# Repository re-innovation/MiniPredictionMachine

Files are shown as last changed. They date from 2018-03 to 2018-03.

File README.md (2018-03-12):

# MiniPredictionMachine
Arduino based weather sensor unit with solar PV charing and an ESP8266 based receiver unit.

This repository holds the KiCAD PCB design files and the various .dxf files for the hardware.

This repository is for information only and is not maintained.

Please see: https://www.re-innovation.co.uk/ for more information.

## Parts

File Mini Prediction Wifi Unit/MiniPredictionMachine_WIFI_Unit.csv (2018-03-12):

Reference | Value | Footprint | Datasheet | Description | Supplier 1 | Supplier 1 Part No | Supplier 1 Cost | Manufacturer | Manufacturer Part No
U1 | NODEMCU | REInnovationFootprint:NodeMCU_Amica_R2_FSILK
DISP1 | OLED_I2C | REInnovationFootprint:TH_OLED1306
D2 | A | REInnovationFootprint:TH_LED-5MM_larg_pad
D3 | B | REInnovationFootprint:TH_LED-5MM_larg_pad
SW1 | SWUP | REInnovationFootprint:SW_PUSH_SMALL_lg_pad
SW2 | SWDOWN | REInnovationFootprint:SW_PUSH_SMALL_lg_pad
P1 | SERIAL_HC12 | REInnovationFootprint:TH_SIL_5_1mm
R1 | 330 | REInnovationFootprint:TH_Resistor_1
R2 | 330 | REInnovationFootprint:TH_Resistor_1
R4 | 10k | REInnovationFootprint:TH_Resistor_1
R3 | 10k | REInnovationFootprint:TH_Resistor_1
CON1 | BARREL_JACK | REInnovationFootprint:DC_Power_2_1
D1 | WS2811_EpiStar_8mm | REInnovationFootprint:TH_WS2811_LED_8mm
SW3 | ON/OFF | REInnovationFootprint:SW_SPDT_R_Angle_ALIEX
F1 | 500mA | REInnovationFootprint:TH_MC36188_FUSE |  | Resettable fuse. 0.5A | RS | 517-6635 | 0.27
D4 | D_Schottky | REInnovationFootprint:TH_Diode_1
P2 | USB | REInnovationFootprint:TH_USB_B_lg_pad
U2 | L4940V5 | REInnovationFootprint:TO220_7805_Vert | http://docs-europe.electrocomponents.com/webdocs/0028/0900766b80028b09.pdf | 1.5A LDO regulator | RS | 298-8491 |  | STMicroelectronics | L4940V5
D5 | D_Schottky | REInnovationFootprint:TH_Diode_1
C1 | 10u | REInnovationFootprint:C_1V7_TH
C2 | 10u | REInnovationFootprint:C_1V7_TH
P4 | NODEMCU_2 | REInnovationFootprint:TH_SIL-15
P3 | NODEMCU_1 | REInnovationFootprint:TH_SIL-15
U3 | 74LVC1G17 | REInnovationFootprint:SM_SOT-23-5 | http://docs-europe.electrocomponents.com/webdocs/154d/0900766b8154d6d1.pdf
P5 | LOCAL 5V? | matts_components:SIL-2_solder_connect
P6 | WS2812 LED | matts_components:SIL-4_screw_terminals
P7 | PCB | REInnovationFootprint:PCB_50x100mm_RJWIFI
P8 | LOGO1 | CuriousElectric3:CEC_Globe_10mm_FCU
P9 | LOGO2 | CuriousElectric3:TCEC_Words_13mm
P10 | POWER | REInnovationFootprint:SIL-2_screw_terminal

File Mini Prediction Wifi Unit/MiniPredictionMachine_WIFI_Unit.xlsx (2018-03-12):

Reference | Value | Footprint | Datasheet | Description | Supplier 1 | Supplier 1 Part No | Supplier 1 Cost | Manufacturer | Manufacturer Part No | Cost
U1 | NODEMCU | REInnovationFootprint:NodeMCU_Amica_R2_FSILK |  |  |  |  | 8 |  |  | 8
DISP1 | OLED_I2C | REInnovationFootprint:TH_OLED1306 |  |  |  |  | 6 |  |  | 6
D2 | A | REInnovationFootprint:TH_LED-5MM_larg_pad |  |  |  |  | 0.1 |  |  | 0.1
D3 | B | REInnovationFootprint:TH_LED-5MM_larg_pad |  |  |  |  | 0.1 |  |  | 0.1
SW1 | SWUP | REInnovationFootprint:SW_PUSH_SMALL_lg_pad |  |  |  |  | 0.2 |  |  | 0.2
SW2 | SWDOWN | REInnovationFootprint:SW_PUSH_SMALL_lg_pad |  |  |  |  | 0.2 |  |  | 0.2
P1 | SERIAL_HC12 | REInnovationFootprint:TH_SIL_5_1mm |  |  |  |  | 6 |  |  | 6
R1 | 330 | REInnovationFootprint:TH_Resistor_1 |  |  |  |  | 0.01 |  |  | 0.01
R2 | 330 | REInnovationFootprint:TH_Resistor_1 |  |  |  |  | 0.01 |  |  | 0.01
R4 | 10k | REInnovationFootprint:TH_Resistor_1 |  |  |  |  | 0.01 |  |  | 0.01
R3 | 10k | REInnovationFootprint:TH_Resistor_1 |  |  |  |  | 0.01 |  |  | 0.01
CON1 | BARREL_JACK | REInnovationFootprint:DC_Power_2_1 |  |  |  |  | 0.5 |  |  | 0.5
D1 | WS2811_EpiStar_8mm | REInnovationFootprint:TH_WS2811_LED_8mm |  |  |  |  | 0.5 |  |  | 0.5
SW3 | ON/OFF | REInnovationFootprint:SW_SPDT_R_Angle_ALIEX |  |  |  |  | 0.4 |  |  | 0.4
F1 | 500mA | REInnovationFootprint:TH_MC36188_FUSE |  | Resettable fuse. 0.5A | RS | 517-6635 | 0.27 |  |  | 0.27
D4 | D_Schottky | REInnovationFootprint:TH_Diode_1 |  |  |  |  | 0.2 |  |  | 0.2
P2 | USB | REInnovationFootprint:TH_USB_B_lg_pad |  |  |  |  | 1 |  |  | 1
U2 | L4940V5 | REInnovationFootprint:TO220_7805_Vert | http://docs-europe.electrocomponents.com/webdocs/0028/0900766b80028b09.pdf | 1.5A LDO regulator | RS | 298-8491 | 1.2 | STMicroelectronics | L4940V5 | 1.2
D5 | D_Schottky | REInnovationFootprint:TH_Diode_1 |  |  |  |  | 0.2 |  |  | 0.2
C1 | 10u | REInnovationFootprint:C_1V7_TH |  |  |  |  | 0.1 |  |  | 0.1
C2 | 10u | REInnovationFootprint:C_1V7_TH |  |  |  |  | 0.1 |  |  | 0.1
P4 | NODEMCU_2 | REInnovationFootprint:TH_SIL-15 |  |  |  |  |  |  |  | 0
P3 | NODEMCU_1 | REInnovationFootprint:TH_SIL-15 |  |  |  |  |  |  |  | 0
U3 | 74LVC1G17 | REInnovationFootprint:SM_SOT-23-5 | http://docs-europe.electrocomponents.com/webdocs/154d/0900766b8154d6d1.pdf |  |  |  | 0.2 |  |  | 0.2
P5 | LOCAL 5V? | matts_components:SIL-2_solder_connect |  |  |  |  |  |  |  | 0
P6 | WS2812 LED | matts_components:SIL-4_screw_terminals |  |  |  |  |  |  |  | 0
P7 | PCB | REInnovationFootprint:PCB_50x100mm_RJWIFI |  |  |  |  |  |  |  | 0
P8 | LOGO1 | CuriousElectric3:CEC_Globe_10mm_FCU |  |  |  |  |  |  |  | 0
P9 | LOGO2 | CuriousElectric3:TCEC_Words_13mm |  |  |  |  |  |  |  | 0
P10 | POWER | REInnovationFootprint:SIL-2_screw_terminal |  |  |  |  |  |  |  | 0
 | PCB |  |  |  |  |  | 3 |  |  | 3
 | Enclosure? |  |  |  |  |  | 8 |  |  | 8
 |  |  |  |  |  |  |  |  |  | 0
 |  |  |  |  |  |  |  |  | Total Cost = | 36.31
 |  |  |  |  |  |  |  |  | Contingency (20%) | 7.262
 |  |  |  |  |  |  |  |  | Total = | 43.572

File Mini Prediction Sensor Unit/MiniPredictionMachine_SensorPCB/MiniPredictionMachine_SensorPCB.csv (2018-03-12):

Reference | Value | Footprint | Datasheet | Description | Supplier 1 | Supplier 1 Part No | Supplier 1 Cost | Manufacturer | Manufacturer Part No
P1 | SOLAR | REInnovationFootprint:SIL_2_screw_+_JST_2mm
PCB1 | CONN_1 | REInnovationFootprint:PCB_85x120_4hole_EdgeCut
LOGO1 | CONN_1 | CuriousElectric3:CEC_Globe_10mm_FCU
P8 | I2C_1 | matts_components:SIL-4_Grove_SIL
P9 | I2C_2 | matts_components:SIL-4_Grove_SIL
P12 | S_SERIAL | matts_components:SIL-4_Grove_SIL
R6 | 100k | REInnovationFootprint:TH_Resistor_1
R7 | 100k | REInnovationFootprint:TH_Resistor_1
P2 | ANEMOMETER | REInnovationFootprint:SIL-2_screw_terminal
R4 | 10k | REInnovationFootprint:TH_Resistor_1
P6 | VANE | REInnovationFootprint:SIL-2_screw_terminal
SW1 | INPUT B | REInnovationFootprint:SW_PUSH_SMALL_lg_pad
SW2 | INPUT A | REInnovationFootprint:SW_PUSH_SMALL_lg_pad
D2 | LED | REInnovationFootprint:TH_WS2811_LED_8mm
EN1 | CONN_1 |  | http://www.hellermanntyton.co.uk/binaries/content/assets/local-pdf-files/uk/enclosure-solutions/new-enclosures/junction_boxes.pdf | Enclosure for circuit. 162x116x76mm | CPC | EN83296 | 4.26
LOGO2 | CONN_1 | CuriousElectric3:TCEC_Words_13mm
P3 | RAIN | REInnovationFootprint:SIL-2_screw_terminal
P4 | WATER | REInnovationFootprint:SIL-3_screw_terminal
P5 | TEMPERATURE | REInnovationFootprint:SIL-3_screw_terminal
P11 | SERIAL_HC12 | matts_components:SIL-5_large_pads_marker
BT1 | LiPo 18650 | REInnovationFootprint:TH_LiIon_Holder
D4 | D_Schottky | REInnovationFootprint:TH_Diode_1
P7 | VREF? | REInnovationFootprint:SIL-3_solder_connect
R2 | 10k | REInnovationFootprint:TH_Resistor_1
R1 | 10k | REInnovationFootprint:TH_Resistor_1
R3 | 4k7 | REInnovationFootprint:TH_Resistor_1
D3 | DATA | REInnovationFootprint:TH_LED-5MM_larg_pad
R5 | 330 | REInnovationFootprint:TH_Resistor_1
P16 | GPS MODULE | matts_components:SIL-5_large_pads_marker
R15 | 1k | REInnovationFootprint:TH_Resistor_1
R16 | 100k | REInnovationFootprint:TH_Resistor_1
Q2 | BD135 | REInnovationFootprint:TO220_BD135
P15 | AIO_67 | matts_components:SIL-4_Grove_SIL
SERIAL1 | CONN_1 |  | https://www.elecrow.com/433mhz-serial-rf-module-hc12-1000m-p-874.html |  | Elecrow | WHC0012RF | 5.23
P17 | USB | REInnovationFootprint:SIL-2_screw_terminal
U1 | BQ24210 | REInnovationFootprint:SM_WSON-10-2x3 | http://www.ti.com/lit/ds/symlink/bq24210.pdf | LiIon Charger 800mA PV Input | RS | 742-2836 | 2.34 | TI | BQ24210DQCT
R12 | 2.2k | REInnovationFootprint:TH_Resistor_1
R13 | 2.2k | REInnovationFootprint:TH_Resistor_1
C1 | 1uF | REInnovationFootprint:C_1V7_TH
C2 | 1uF | REInnovationFootprint:C_1V7_TH
R10 | 1k | REInnovationFootprint:TH_Resistor_1
R11 | 100k | REInnovationFootprint:TH_Resistor_1
D7 | CHG | REInnovationFootprint:TH_LED-5MM_larg_pad
D8 | PG | REInnovationFootprint:TH_LED-5MM_larg_pad
C4 | 10uF | REInnovationFootprint:C_1V7_TH
C3 | 10uF | REInnovationFootprint:C_1V7_TH
U2 | MCP1826S | REInnovationFootprint:TO220_MCP1826S
SW3 | ON/OFF | REInnovationFootprint:SW_SPDT_R_Angle_ALIEX
F1 | 500mA | REInnovationFootprint:TH_MC36188_FUSE |  | Resettable fuse. 0.5A | RS | 517-6635 | 0.27
D6 | D_Schottky | REInnovationFootprint:TH_Diode_1
C7 | 100nF | matts_components:C1_wide_lg_pad
C6 | 100nF | matts_components:C1_wide_lg_pad
C5 | 100uF | REInnovationFootprint:C_1V7_TH
SW4 | RESET | matts_components:SW_PUSH_single_pins
C9 | 22pF | matts_components:C1_lg_pad
C8 | 22pF | matts_components:C1_lg_pad
R14 | 10k | REInnovationFootprint:TH_Resistor_1
X1 | 16MHz | matts_components:Xtal_small_matt
P14 | FTDI | matts_components:SIL-6_large_pads_marker
P13 | ISP | matts_components:ISP_3x2
IC1 | ATMEGA328P-P | REInnovationFootprint:DIP-28__300_ELL
J1 | NANO | REInnovationFootprint:NANO_DIP_30_600

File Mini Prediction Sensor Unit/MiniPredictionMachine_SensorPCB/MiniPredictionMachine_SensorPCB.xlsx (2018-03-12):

Reference | Value | Footprint | Datasheet | Description | Supplier 1 | Supplier 1 Part No | Supplier 1 Cost | Manufacturer | Manufacturer Part No | Total Cost
P1 | SOLAR | REInnovationFootprint:SIL_2_screw_+_JST_2mm |  |  |  |  | 10 |  |  | 0
PCB1 | CONN_1 | REInnovationFootprint:PCB_85x120_4hole_EdgeCut |  |  |  |  |  |  |  | 0
LOGO1 | CONN_1 | CuriousElectric3:CEC_Globe_10mm_FCU |  |  |  |  |  |  |  | 0
P8 | I2C_1 | matts_components:SIL-4_Grove_SIL |  |  |  |  |  |  |  | 0
P9 | I2C_2 | matts_components:SIL-4_Grove_SIL |  |  |  |  |  |  |  | 0
P12 | S_SERIAL | matts_components:SIL-4_Grove_SIL |  |  |  |  |  |  |  | 0
R6 | 100k | REInnovationFootprint:TH_Resistor_1 |  |  |  |  | 0.02 |  |  | 0.02
R7 | 100k | REInnovationFootprint:TH_Resistor_1 |  |  |  |  | 0.02 |  |  | 0.02
P2 | ANEMOMETER | REInnovationFootprint:SIL-2_screw_terminal |  |  |  |  |  |  |  | 0
R4 | 10k | REInnovationFootprint:TH_Resistor_1 |  |  |  |  | 0.02 |  |  | 0.02
P6 | VANE | REInnovationFootprint:SIL-2_screw_terminal |  |  |  |  |  |  |  | 0
SW1 | INPUT B | REInnovationFootprint:SW_PUSH_SMALL_lg_pad |  |  |  |  | 0.1 |  |  | 0.1
SW2 | INPUT A | REInnovationFootprint:SW_PUSH_SMALL_lg_pad |  |  |  |  | 0.1 |  |  | 0.1
D2 | LED | REInnovationFootprint:TH_WS2811_LED_8mm |  |  |  |  | 0.5 |  |  | 0.5
EN1 | CONN_1 |  | http://www.hellermanntyton.co.uk/binaries/content/assets/local-pdf-files/uk/enclosure-solutions/new-enclosures/junction_boxes.pdf | Enclosure for circuit. 162x116x76mm | CPC | EN83296 | 4.26 |  |  | 4.26
LOGO2 | CONN_1 | CuriousElectric3:TCEC_Words_13mm |  |  |  |  |  |  |  | 0
P3 | RAIN | REInnovationFootprint:SIL-2_screw_terminal |  |  |  |  |  |  |  | 0
P4 | WATER | REInnovationFootprint:SIL-3_screw_terminal |  |  |  |  |  |  |  | 0
P5 | TEMPERATURE | REInnovationFootprint:SIL-3_screw_terminal |  |  |  |  |  |  |  | 0
P11 | SERIAL_HC12 | matts_components:SIL-5_large_pads_marker |  |  |  |  | 8 |  |  | 8
BT1 | LiPo 18650 | REInnovationFootprint:TH_LiIon_Holder |  |  |  |  | 5 |  |  | 5
D4 | D_Schottky | REInnovationFootprint:TH_Diode_1 |  |  |  |  | 0.1 |  |  | 0.1
P7 | VREF? | REInnovationFootprint:SIL-3_solder_connect |  |  |  |  |  |  |  | 0
R2 | 10k | REInnovationFootprint:TH_Resistor_1 |  |  |  |  | 0.02 |  |  | 0.02
R1 | 10k | REInnovationFootprint:TH_Resistor_1 |  |  |  |  | 0.02 |  |  | 0.02
R3 | 4k7 | REInnovationFootprint:TH_Resistor_1 |  |  |  |  | 0.02 |  |  | 0.02
D3 | DATA | REInnovationFootprint:TH_LED-5MM_larg_pad |  |  |  |  |  |  |  | 0
R5 | 330 | REInnovationFootprint:TH_Resistor_1 |  |  |  |  | 0.02 |  |  | 0.02
P16 | GPS MODULE | matts_components:SIL-5_large_pads_marker |  |  |  |  |  |  |  | 0
R15 | 1k | REInnovationFootprint:TH_Resistor_1 |  |  |  |  | 0.02 |  |  | 0.02
R16 | 100k | REInnovationFootprint:TH_Resistor_1 |  |  |  |  | 0.02 |  |  | 0.02
Q2 | BD135 | REInnovationFootprint:TO220_BD135 |  |  |  |  | 0.3 |  |  | 0.3
P15 | AIO_67 | matts_components:SIL-4_Grove_SIL |  |  |  |  |  |  |  | 0
SERIAL1 | CONN_1 |  | https://www.elecrow.com/433mhz-serial-rf-module-hc12-1000m-p-874.html |  | Elecrow | WHC0012RF | 5.23 |  |  | 5.23
P17 | USB | REInnovationFootprint:SIL-2_screw_terminal |  |  |  |  |  |  |  | 0
U1 | BQ24210 | REInnovationFootprint:SM_WSON-10-2x3 | http://www.ti.com/lit/ds/symlink/bq24210.pdf | LiIon Charger 800mA PV Input | RS | 742-2836 | 2.34 | TI | BQ24210DQCT | 2.34
R12 | 2.2k | REInnovationFootprint:TH_Resistor_1 |  |  |  |  | 0.02 |  |  | 0.02
R13 | 2.2k | REInnovationFootprint:TH_Resistor_1 |  |  |  |  | 0.02 |  |  | 0.02
C1 | 1uF | REInnovationFootprint:C_1V7_TH |  |  |  |  | 0.1 |  |  | 0.1
C2 | 1uF | REInnovationFootprint:C_1V7_TH |  |  |  |  | 0.1 |  |  | 0.1
R10 | 1k | REInnovationFootprint:TH_Resistor_1 |  |  |  |  | 0.02 |  |  | 0.02
R11 | 100k | REInnovationFootprint:TH_Resistor_1 |  |  |  |  | 0.02 |  |  | 0.02
D7 | CHG | REInnovationFootprint:TH_LED-5MM_larg_pad |  |  |  |  | 0.1 |  |  | 0.1
D8 | PG | REInnovationFootprint:TH_LED-5MM_larg_pad |  |  |  |  | 0.1 |  |  | 0.1
C4 | 10uF | REInnovationFootprint:C_1V7_TH |  |  |  |  | 0.1 |  |  | 0.1
C3 | 10uF | REInnovationFootprint:C_1V7_TH |  |  |  |  | 0.1 |  |  | 0.1
U2 | MCP1826S | REInnovationFootprint:TO220_MCP1826S |  |  |  |  | 1 |  |  | 1
SW3 | ON/OFF | REInnovationFootprint:SW_SPDT_R_Angle_ALIEX |  |  |  |  | 0.2 |  |  | 0.2
F1 | 500mA | REInnovationFootprint:TH_MC36188_FUSE |  | Resettable fuse. 0.5A | RS | 517-6635 | 0.27 |  |  | 0.27
D6 | D_Schottky | REInnovationFootprint:TH_Diode_1 |  |  |  |  | 0.2 |  |  | 0.2
C7 | 100nF | matts_components:C1_wide_lg_pad |  |  |  |  | 0.1 |  |  | 0.1
C6 | 100nF | matts_components:C1_wide_lg_pad |  |  |  |  | 0.1 |  |  | 0.1
C5 | 100uF | REInnovationFootprint:C_1V7_TH |  |  |  |  | 0.1 |  |  | 0.1
SW4 | RESET | matts_components:SW_PUSH_single_pins |  |  |  |  | 0.1 |  |  | 0.1
C9 | 22pF | matts_components:C1_lg_pad |  |  |  |  | 0.1 |  |  | 0.1
C8 | 22pF | matts_components:C1_lg_pad |  |  |  |  | 0.1 |  |  | 0.1
R14 | 10k | REInnovationFootprint:TH_Resistor_1 |  |  |  |  | 0.02 |  |  | 0.02
X1 | 16MHz | matts_components:Xtal_small_matt |  |  |  |  |  |  |  | 0
P14 | FTDI | matts_components:SIL-6_large_pads_marker |  |  |  |  |  |  |  | 0
P13 | ISP | matts_components:ISP_3x2 |  |  |  |  |  |  |  | 0
IC1 | ATMEGA328P-P | REInnovationFootprint:DIP-28__300_ELL |  |  |  |  |  |  |  | 0
J1 | NANO | REInnovationFootprint:NANO_DIP_30_600 |  |  |  |  | 6 |  |  | 6
 | PCB |  |  |  |  |  | 3 |  |  | 3
 | Enclosure |  |  |  |  |  | 8 |  |  | 8
 |  |  |  |  |  |  |  |  |  | 0
 |  |  |  |  |  |  |  |  |  | 0
 |  |  |  |  |  |  |  |  | Total parts cost | 46.08
 |  |  |  |  |  |  |  |  | Contingency (20%) | 9.216
 |  |  |  |  |  |  |  |  |  | 55.296

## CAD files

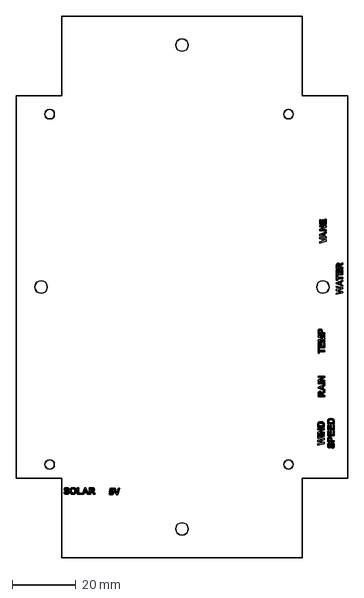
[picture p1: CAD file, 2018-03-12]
Mini Prediction Sensor Unit/Hardware/2017_07_31_Weather_Sensor_Baseplate.dxf
104.0 x 170.0 mm

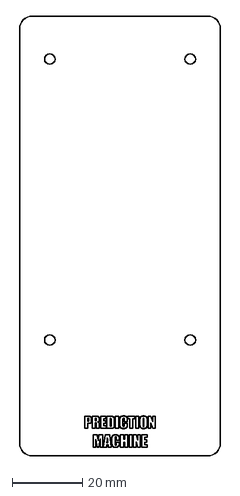
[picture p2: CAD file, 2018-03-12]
Mini Prediction Wifi Unit/Hardware/WifiUnitBasePlate.dxf
57.2 x 125.2 mm

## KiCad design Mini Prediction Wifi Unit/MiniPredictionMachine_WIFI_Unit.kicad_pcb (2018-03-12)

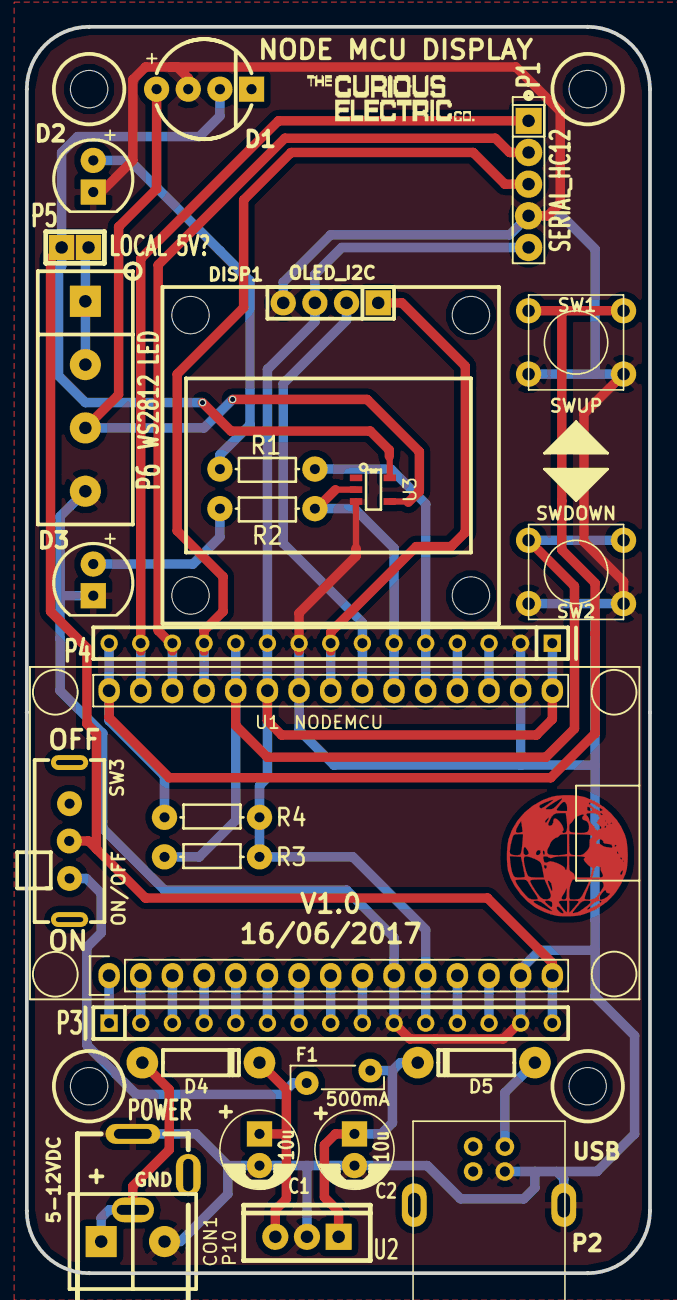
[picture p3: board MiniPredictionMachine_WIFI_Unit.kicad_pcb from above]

Board: 2 copper layers, 50.0 x 100.0 mm, 30 parts (0 on the bottom side), 34 nets.

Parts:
C1, C2: 10u; C_1V7_TH
CON1: BARREL_JACK; DC_Power_2_1
D1: WS2811_EpiStar_8mm; TH_WS2811_LED_8mm
D2: A; TH_LED-5MM_larg_pad
D3: B; TH_LED-5MM_larg_pad
D4, D5: D_Schottky; TH_Diode_1
DISP1: OLED_I2C; TH_OLED1306
F1: 500mA; TH_MC36188_FUSE
P1: SERIAL_HC12; TH_SIL_5_1mm
P2: USB; TH_USB_B_lg_pad
P3: NODEMCU_1; TH_SIL-15
P4: NODEMCU_2; TH_SIL-15
P5: LOCAL 5V?; SIL-2_solder_connect
P6: WS2812 LED; SIL-4_screw_terminals
P7: PCB; PCB_50x100mm_RJWIFI
P8: LOGO1; CEC_Globe_10mm_FCU
P9: LOGO2; TCEC_Words_13mm
P10: POWER; SIL-2_screw_terminal
R1, R2: 330; TH_Resistor_1
R3, R4: 10k; TH_Resistor_1
SW1: SWUP; SW_PUSH_SMALL_lg_pad
SW2: SWDOWN; SW_PUSH_SMALL_lg_pad
SW3: ON/OFF; SW_SPDT_R_Angle_ALIEX
U1: NODEMCU; NodeMCU_Amica_R2_FSILK
U2: L4940V5; TO220_7805_Vert
U3: 74LVC1G17; SM_SOT-23-5

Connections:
+3V3: DISP1.3, P1.5, P3.11, P4.1, P4.10, R3.2, R4.2, U1.11, U1.16, U1.25
/5V_PWR: D1.2, P3.15, P5.1, SW3.2, U1.15, U3.5
/HC12_SET: P1.1, P4.14, U1.29
/LED_A: P4.5, R1.1, U1.20
/LED_WS2811: P4.6, R2.1, U1.21, U3.2
/Rx: P4.4, U1.19
/SCL: DISP1.2, P4.7, U1.22
/SDA: DISP1.1, P4.8, U1.23
/SOFT_Rx: P1.2, P4.13, U1.28
/SOFT_Tx: P1.3, P4.12, U1.27
/SW_DOWN: P4.11, R3.1, SW2.1, U1.26
/SW_UP: P4.15, R4.1, SW1.1, U1.30
/Tx: P4.3, U1.18
GND: C1.2, C2.2, CON1.2, D1.3, D2.1, D3.1, DISP1.4, P1.4, P2.4, P2.5, P3.10, P3.14, P4.2, P4.9, P6.4, P10.2, SW1.2, SW2.2, U1.10, U1.14, U1.17, U1.24, U2.GND, U3.3
unnamed: C1.1, D4.1, U2.VI
unnamed: C2.1, D5.1, F1.1, U2.VO
unnamed: CON1.1, D4.2, P10.1
unnamed: D1.4, P6.3, U3.4
unnamed: D2.2, R1.2
unnamed: D3.2, R2.2
unnamed: D5.2, P2.1
unnamed: F1.2, SW3.1
unnamed: P3.1, U1.1
unnamed: P3.2, U1.2
unnamed: P3.3, U1.3
unnamed: P3.4, U1.4
unnamed: P3.5, U1.5
unnamed: P3.6, U1.6
unnamed: P3.7, U1.7
unnamed: P3.8, U1.8
unnamed: P3.9, U1.9
unnamed: P3.12, U1.12
unnamed: P3.13, U1.13
unnamed: P5.2, P6.1, P6.2

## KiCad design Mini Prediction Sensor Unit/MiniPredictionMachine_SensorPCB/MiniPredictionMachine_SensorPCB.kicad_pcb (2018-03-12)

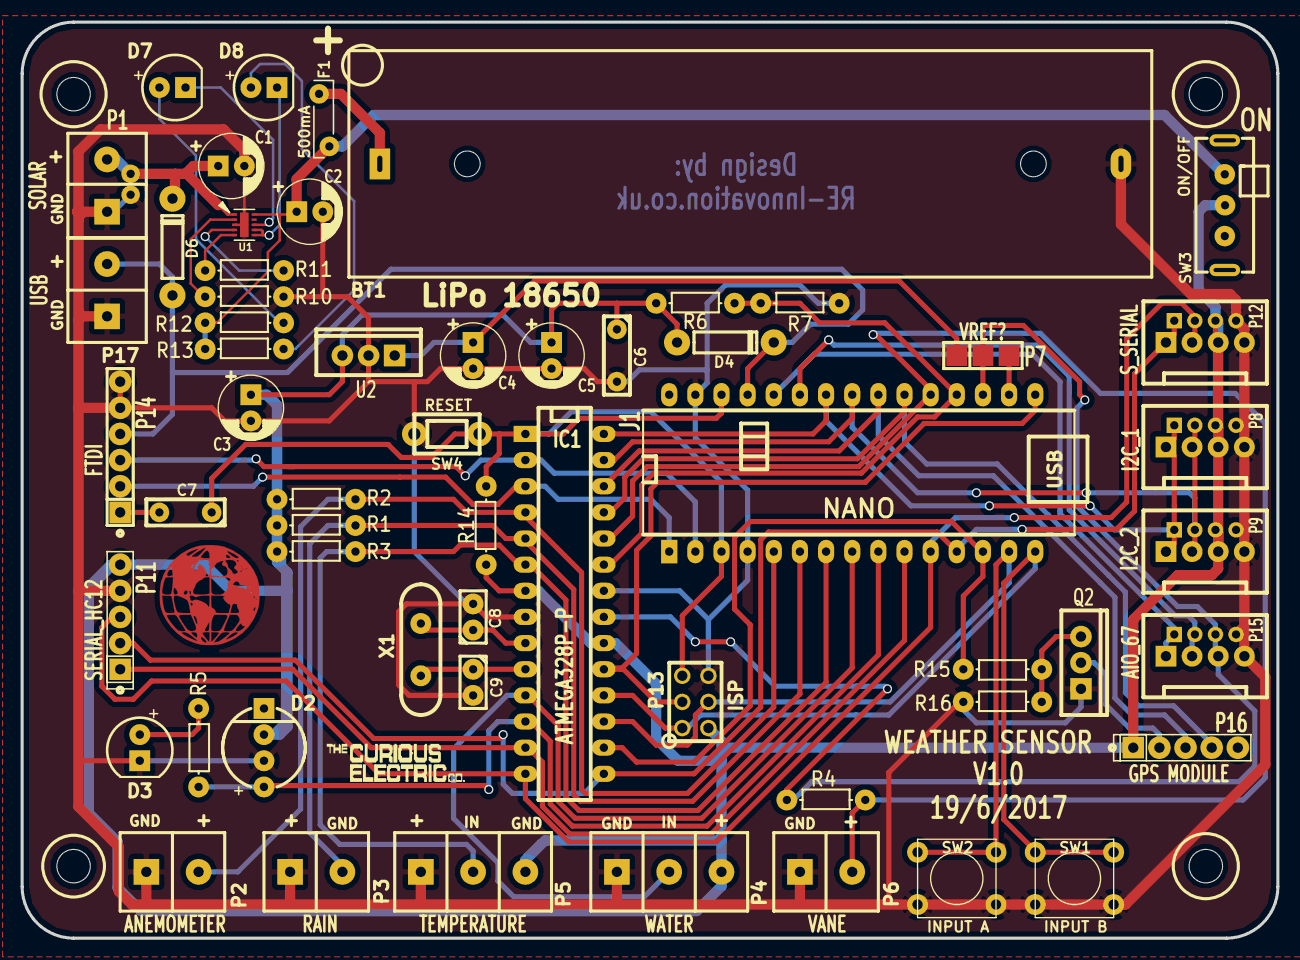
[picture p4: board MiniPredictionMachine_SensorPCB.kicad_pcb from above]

Board: 2 copper layers, 122.0 x 89.0 mm, 60 parts (0 on the bottom side), 45 nets.

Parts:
BT1: LiPo 18650; TH_LiIon_Holder
C1, C2: 1uF; C_1V7_TH
C3, C4: 10uF; C_1V7_TH
C5: 100uF; C_1V7_TH
C6, C7: 100nF; C1_wide_lg_pad
C8, C9: 22pF; C1_lg_pad
D2: LED; TH_WS2811_LED_8mm
D3: DATA; TH_LED-5MM_larg_pad
D4, D6: D_Schottky; TH_Diode_1
D7: CHG; TH_LED-5MM_larg_pad
D8: PG; TH_LED-5MM_larg_pad
F1: 500mA; TH_MC36188_FUSE
IC1: ATMEGA328P-P; DIP-28__300_ELL
J1: NANO; NANO_DIP_30_600
LOGO1: CONN_1; CEC_Globe_10mm_FCU
LOGO2: CONN_1; TCEC_Words_13mm
P1: SOLAR; SIL_2_screw_+_JST_2mm
P2: ANEMOMETER; SIL-2_screw_terminal
P3: RAIN; SIL-2_screw_terminal
P4: WATER; SIL-3_screw_terminal
P5: TEMPERATURE; SIL-3_screw_terminal
P6: VANE; SIL-2_screw_terminal
P7: VREF?; SIL-3_solder_connect
P8: I2C_1; SIL-4_Grove_SIL
P9: I2C_2; SIL-4_Grove_SIL
P11: SERIAL_HC12; SIL-5_large_pads_marker
P12: S_SERIAL; SIL-4_Grove_SIL
P13: ISP; ISP_3x2
P14: FTDI; SIL-6_large_pads_marker
P15: AIO_67; SIL-4_Grove_SIL
P16: GPS MODULE; SIL-5_large_pads_marker
P17: USB; SIL-2_screw_terminal
PCB1: CONN_1; PCB_85x120_4hole_EdgeCut
Q2: BD135; TO220_BD135
R1, R2, R4, R14: 10k; TH_Resistor_1
R3: 4k7; TH_Resistor_1
R5: 330; TH_Resistor_1
R6, R7, R11, R16: 100k; TH_Resistor_1
R10, R15: 1k; TH_Resistor_1
R12, R13: 2.2k; TH_Resistor_1
SW1: INPUT B; SW_PUSH_SMALL_lg_pad
SW2: INPUT A; SW_PUSH_SMALL_lg_pad
SW3: ON/OFF; SW_SPDT_R_Angle_ALIEX
SW4: RESET; SW_PUSH_single_pins
U1: BQ24210; SM_WSON-10-2x3
U2: MCP1826S; TO220_MCP1826S
X1: 16MHz; Xtal_small_matt

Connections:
+3.3V: IC1.21, J1.18, P7.2, P15.3, R4.1
/A6: J1.25, P15.2
/A7: J1.26, P15.1
/Arduino Nano or IC/3V3_NANO: J1.17, P7.3
/Arduino Nano or IC/D13: IC1.19, J1.16, P13.3
/GPS_CS: IC1.16, J1.13, R15.2
/LED_WS2811: D2.4, IC1.12, J1.9, R5.2
/MOISTURE: IC1.11, J1.8, P4.2
/RAIN_FALL: IC1.5, J1.6, P3.2, R1.2
/Rx: IC1.2, J1.2, P14.3
/Rx_SOFT: IC1.15, J1.12, P11.2, P12.1
/Rx_SOFT2: IC1.26, J1.22, P16.3
/SCLK: IC1.28, J1.24, P8.1, P9.1
/SDA: IC1.27, J1.23, P8.2, P9.2
/SW_A: IC1.17, J1.14, P13.4, SW2.1
/SW_B: IC1.18, J1.15, P13.1, SW1.1
/Solar Charging/3V3: C4.1, P7.1, U2.3
/Solar Charging/LiPoOUT+: BT1.1, F1.2
/Solar Charging/PVIN+: C1.1, D6.1, P1.2, U1.1
/TEMPERATURE: IC1.6, J1.7, P5.2, R3.2
/Tx: IC1.3, J1.1, P14.2
/Tx_SOFT: IC1.14, J1.11, P11.3, P12.2
/Tx_SOFT2: IC1.25, J1.21, P16.4
/VANE: IC1.24, J1.20, P6.2, R4.2
/VBATT: IC1.23, J1.19, R6.2, R7.1
/VUSB: D4.1, D6.2, J1.27, P14.4, P17.2
/Vss: C3.1, C5.1, C6.1, D2.2, D4.2, IC1.7, IC1.20, P4.3, P5.3, P8.3, P9.3, P11.5, P12.3, P13.2, P16.1, R1.1, R2.1, R3.1, R6.1, R14.1, SW3.2, U2.1
/WIND_SPEED: IC1.4, J1.5, P2.2, R2.2
/WIRELESS_CS: IC1.13, J1.10, P11.1
GND: BT1.2, C1.2, C2.2, C3.2, C4.2, C5.2, C6.2, C8.2, C9.2, D2.3, D3.1, IC1.8, IC1.22, J1.4, J1.29, P1.1, P2.1, P3.1, P4.1, P5.1, P6.1, P8.4, P9.4, P11.4, P12.4, P13.6, P14.5, P14.6, P15.4, P17.1, Q2.1, R7.2, R10.2, R16.1, SW1.2, SW2.2, SW4.2, U1.3, U1.PAD, U2.2
unnamed: C2.1, F1.1, R12.1, R13.1, SW3.1, U1.10
unnamed: C7.2, P14.1
unnamed: C8.1, IC1.9, X1.2
unnamed: C9.1, IC1.10, X1.1
unnamed: D3.2, R5.1
unnamed: D7.1, U1.8
unnamed: D7.2, R12.2
unnamed: D8.1, U1.6, U1.7
unnamed: D8.2, R13.2
unnamed: P16.2, Q2.2
unnamed: Q2.3, R15.1, R16.2
unnamed: R10.1, U1.2
unnamed: R11.1, U1.5
unnamed: R11.2, U1.4
RESET: C7.1, IC1.1, J1.3, J1.28, P13.5, R14.2, SW4.1
